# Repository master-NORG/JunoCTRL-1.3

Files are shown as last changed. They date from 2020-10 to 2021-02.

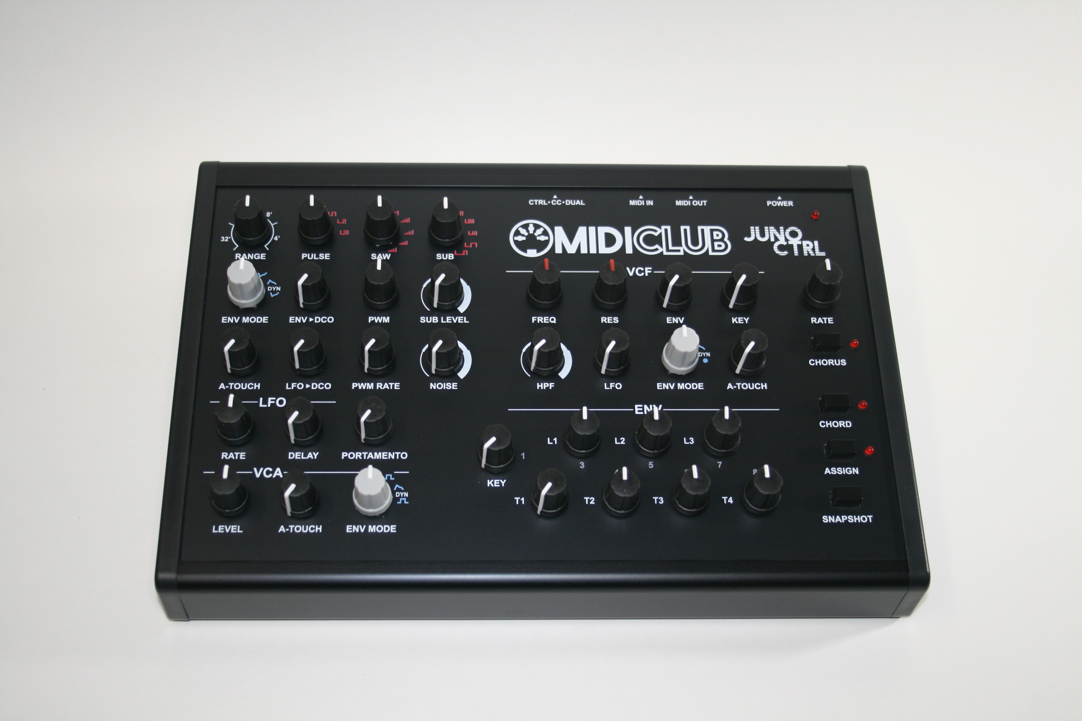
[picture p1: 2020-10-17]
JunoCTRL Photos/IMG_0346.JPG

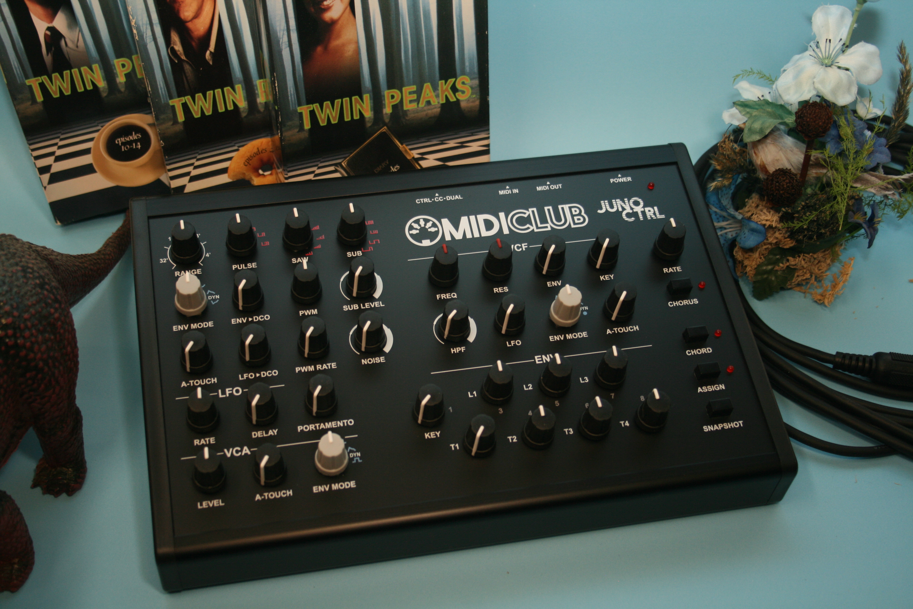
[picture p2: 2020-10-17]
JunoCTRL Photos/IMG_0430.JPG

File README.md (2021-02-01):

# JunoCTRL-1.3
Alpha Juno Hardware Controller

This is the repository for the JunoCTRL Alpha Juno controller from MIDI , which was released in 2015 and slowly upgraded and developed over the years until 2020.  You may use these files if you want to make your own JunoCTRL, modify your unit or would like to make a batch to bring down the price of components.  Be aware that I wrote the firmware 6 years ago when I knew almost nothing about C++ programming, it's awful to look at.  However, it works well, performs well and is bug-free.

I am not going to spend the time to document this project better, not that I don't want to, I just don't have the time. Although MIDI Club is no longer a thing, you can still reach us for questions about this project anytime at midiclub604@gmail.com

Note: there are two pcb boards, the main board and the smaller rear board for the switches, power and midi sockets. If you are making a JunoCTRL with the DIY acrylic case then you only need the main board and not the rear PCB.

Happy hacking!

-Dylan

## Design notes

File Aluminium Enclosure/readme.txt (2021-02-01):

send these files to Takashi Enclosure in Japan to have a case made.  CF27-18BB is the case we use, it's a sturdy black aluminium case.  Takashi Enclosure is great, I've never had a single issue with any of their orders and they are fast.

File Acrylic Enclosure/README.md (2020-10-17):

# junoctrl
JunoCTRL Acrylic Case Files

//In this folder are two files for making an acrylic laser cut case for the JunoCTRL.  They are Adobe Illustrator files and most laser cutting and printing service providers will be able to use these.  You will need to aquire one panel of 3mm thick (very important) matte acrylic and it must be approximately 21" x 12" in size.  I highly recommend using matte acrylic and not glossy, because glossy is too reflective and tends to pick up a lot of fingerprints and dust quickly.

//Printing**  You will need to print the graphics on the acrylic panel first before laser cutting.  The printing must be perfectly aligned since the laser cutting depends on it.  The graphics include a few cross hairs for proper alignment.  So for the type of printing we went with UV printing because it is the least expensive, however UV printing is not as permanent as screen printed graphics, so go with whichever method you prefer, either works fine.  If you do go with UV printing be very careful while transporting the printed panels to make sure the graphics don't get scratched off at any point. You will also notice in the printing file there is a layer that is all white and then the layers with colour, this is because the UV printing on black or dark colours needs a white surface to print on.  So the UV printer will do a layer of white and then the colour layers directly over top of them.

//Laser Cutting**  Most laser cutting service providers will be able to work with the large file, but keep in mind they must align it properly using the hair triggers to calibrate their cut.  The front panel is closet to the top of the file because this part must be cut as straight as possible, the side and rear panels do not need to be as perfect which is why they are near the bottom.

//Final notes** I have occasionally ordered 3mm plastic and received plastic that was 4.5mm thick.  If this is the case you may need to sand down the teeth on the pieces so everything fits.  Be sure the acrylic you order has no more than a +-0.5mm tolerance.

//Feel free to email me at info@midiclub.net if you have any questions regarding the process of making your own acrylic case for the JunoCTRL.  Cheers!  -Dylan

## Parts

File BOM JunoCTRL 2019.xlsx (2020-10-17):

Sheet: Sheet1
BOM JunoCTRL 2019
# | Qty |  | Part | Mrf: # | Source
D01 | 1 | A | 1N4148 Diode | 78-1N4148-TAP | Mouser
DC | 1 | A | DC Socket | 163-7620E-E | Mouser
IC01-04 | 4 | A | P to S Shift Registers (4021) | CD4021BE | Mouser
IC05 | 1 | A | S to P Shift Register (HC595) | SN74HC595N | Mouser
IC06-08 | 3 | A | Analog Multiplexers (4051) | 595-CD4051BE | Mouser
IC08 | 1 | A | Arduino Mini |  | eBay
IC07 | 1 | A | 6N138 Optocoupler | 6N138 | Mouser
L01-04 | 4 | A | 3mm Red LEDs | 859-LTL-4221 | Mouser
N01-02 | 2 | A | DIN-5 Sockets | 161-0504-28A-E | eBay
P01-29 | 29 | A | Rotary Pot 10k |  | Yuwah/Mouser
R01-04 | 4 | A | 2.21K Resistors | 660-MS1/4DCT52R2211 | Mouser
R05-07 | 3 | A | 220 Resistors | 660-MF1/4DCT52R2200F | Mouser
R08 | 1 | A | 1k Resistor | 660-MS1/4DCT52R1001 | Mouser
R09 | 1 | A | 470 Resistor | 660-MF1/4LCT52R471J | Mouser
RN01-04 | 4 | A | 10k 9-Pin Resistor Network | 652-4609X-1LF-10K | Mouser
S01-04 | 4 | N 52 | 4 pos Rotary Switch | SRBV141201 (https://ca.mouser.com/Search/ProductDetail.aspx) | Mouser/Chip1Stop/AVNet Express/E-sonic
S05-06 | 2 | A | 6 pos Rotary Switch | SRBV160803 | Mouser/Chip1Stop/AVNet Express/E-sonic
T01-04 | 4 | N 36 | Tactile Buttons | TL1100F160Q | Mouser/Digikey
W01 | 1 | A | DPDT Slide Switch | 612-EG2208A | Mouser
W02 | 1 | A | DP3T Slide Switch | 612-EG2310 | Mouser/Future Electronics
 | 30 |  | Knobs (Black) |  | Daier/Mouser
 | 3 |  | Knobs (Gray) |  | Daier/Mouser
 | 2 |  | Knobs (Red) |  | Daier/Mouser
 | 4 |  | Tact Switch Cap | 611-F1201 | Mouser
 | 4 | A | 6-32 screws | 36-9903-ND | Digikey
 | 1 |  | Power Supply | 552-PSM03A-090-R | AliExpress/Mouser/eBay/Lees | 9V Center-Positive (at least 400mA output) 2.21mm
 | 1 | A | PCB |  | Seedstudio/DirtyPCB
 | 1 |  | Cases |  | Takashi Enclosures
 | 8 | N 208 | 0.1uF 50v Ceramic Cap | 75-1C10Z5U104M050B | Mouser
 | 1 | A | 47uF 50v Electrolytic Cap | 647-UVZ1H470MED1TD | Mouser
D02 | 1 | A | 1n4002 Diode | 833-1N4002-TP | Mouser
 | 1 | A | L7805 Voltage Regulator | 511-L7805CV | Mouser
P02 | 1 |  | Metal Pot 10k Linear | 688-RK09L1140A66 | Mouser
 | 1 |  | 8 pin IC Sockets | 571-1-2199298-2 | Mouser
 | 8 |  | 16 pin IC Sockets | 571-1-2199298-4 | Mouser
 | 1 |  | Rear PCB board |  | Dirty PCBs
 | 2 |  | Angled Brackets | 36-4334-ND | Digikey | 4334 keystone
 | 4 |  | JST-Sockets |  | Digikey
 | 2 |  | JST-Wires PH8 20cm |  | Ali Express

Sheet: Sheet2
# | Qty |  | Part | x18 | Source | MRF #
D01 | 1 | A | 1N4148 Diode |  | Mouser
DC | 1 | A | DC Jack |  | Mouser
IC01-04 | 4 | A | P to S Shift Registers (4021) |  | Mouser
IC05 | 1 | A | S to P Shift Register (HC595) |  | Mouser
IC06-08 | 3 | A | Analog Multiplexers (4051) |  | Mouser
IC08 | 1 | A | Arduino Mini |  | eBay
IC07 | 1 | A | 6N138 Optocoupler |  | Mouser
L01-04 | 4 | A | 3mm Red LEDs |  | Mouser
N01-02 | 2 | A | DIN-5 Jacks |  | Mouser/Aliexpress
P01-29 | 29 | A | Rotary Pot 10k |  | Yuwah/Mouser
R01-04 | 4 | A | 2.21K Resistors |  | Mouser
R05-07 | 3 | A | 220 Resistors |  | Mouser
R08 | 1 | A | 1k Resistor |  | Mouser
R09 | 1 | A | 470 Resistor |  | Mouser
RN01-04 | 4 | A | 10k 9-Pin Resistor Network |  | Mouser
S01-04 | 4 | N 52 | 4 pos Rotary Switch |  | Mouser/Chip1Stop/AVNet Express
S05-06 | 2 | A | 6 pos Rotary Switch |  | Mouser/Chip1Stop/AVNet Express
T01-04 | 4 | N 36 | Tactile Buttons |  | Mouser/Digikey
W01 | 1 | A | DPDT Slide Switch |  | Mouser
W02 | 1 | A | DP3T Slide Switch |  | Mouser/Future Electronics
 | 30 |  | Knobs (Black) |  | Daier/Mouser
 | 3 |  | Knobs (Gray) |  | Daier/Mouser
 | 2 |  | Knobs (Red) |  | Daier/Mouser
 | 4 |  | Tact Switch Cap |  | Mouser
 | 6 | A | M3x9mm Spacers F/M |  | AliExpress/eBay
 | 7 | A | M3x22mm Spacers F/F |  | AliExpress/eBay
 | 4 | A | 6-32 screws |  | Ali Express
 | 4 |  | Rubber Feet |  | Mouser
 | 1 |  | Power Supply |  | AliExpress/Mouser/eBay/Lees
 | 1 | A | PCB |  | Seedstudio/DirtyPCB
 | 1 |  | Cases |  | Takashi Enclosures
 | 8 | N 208 | 0.1uF 50v Ceramic Cap |  | Mouser
 | 1 | A | 47uF 50v Electrolytic Cap |  | Mouser
D02 | 1 | A | 1n4002 Diode |  | Mouser
 | 1 | A | L7805 Voltage Regulator |  | Mouser
 | 1 |  | 8 pin IC Sockets |  | Mouser
 | 8 |  | 16 pin IC Sockets |  | Mouser
 | 1 |  | Rear PCB board |  | Dirty PCBs
 | 2 |  | Angled Brackets |  | Digikey
 | 2 |  | JST-Sockets |  | Ali Express
 | 2 |  | JST-Wires+Jacks |  | Ali Express

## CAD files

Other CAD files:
Aluminium Enclosure/SlidePanelMilling2.dwg
Aluminium Enclosure/RearPanelMilling.dwg

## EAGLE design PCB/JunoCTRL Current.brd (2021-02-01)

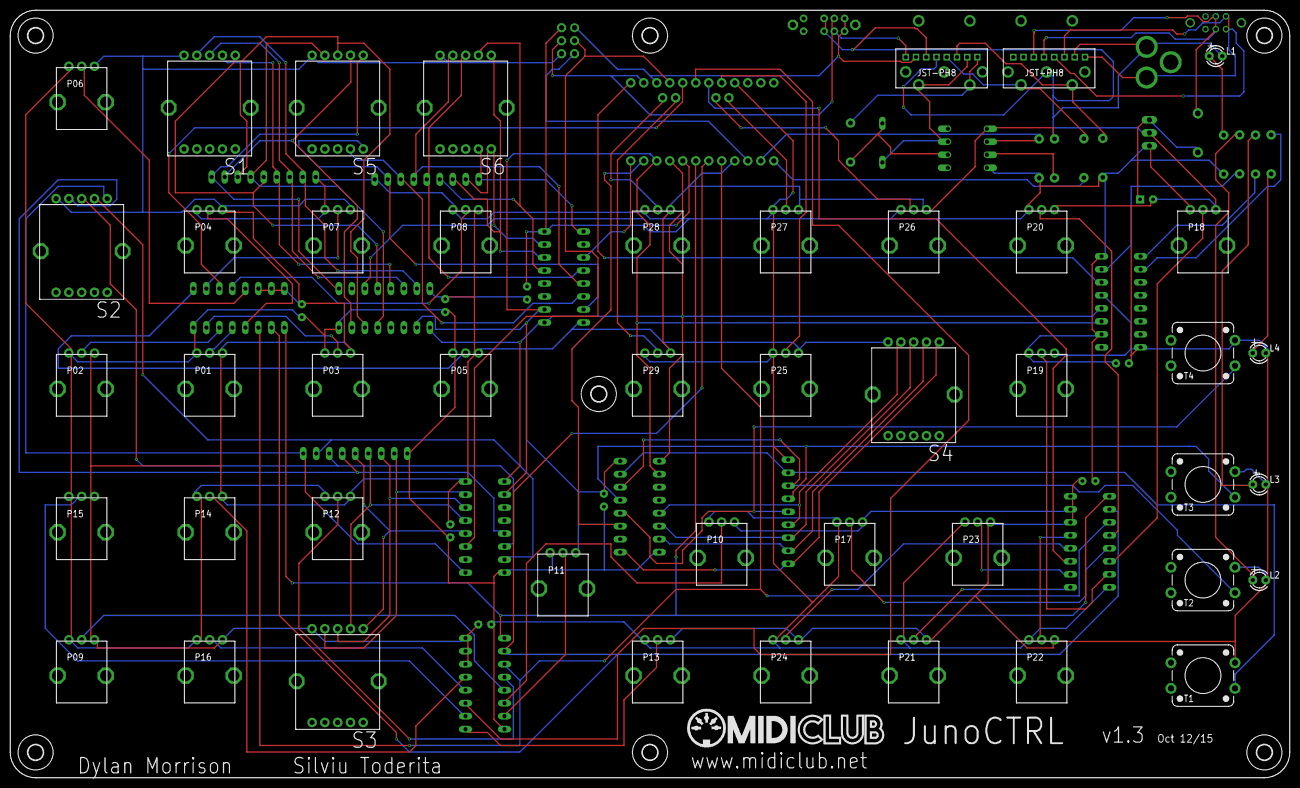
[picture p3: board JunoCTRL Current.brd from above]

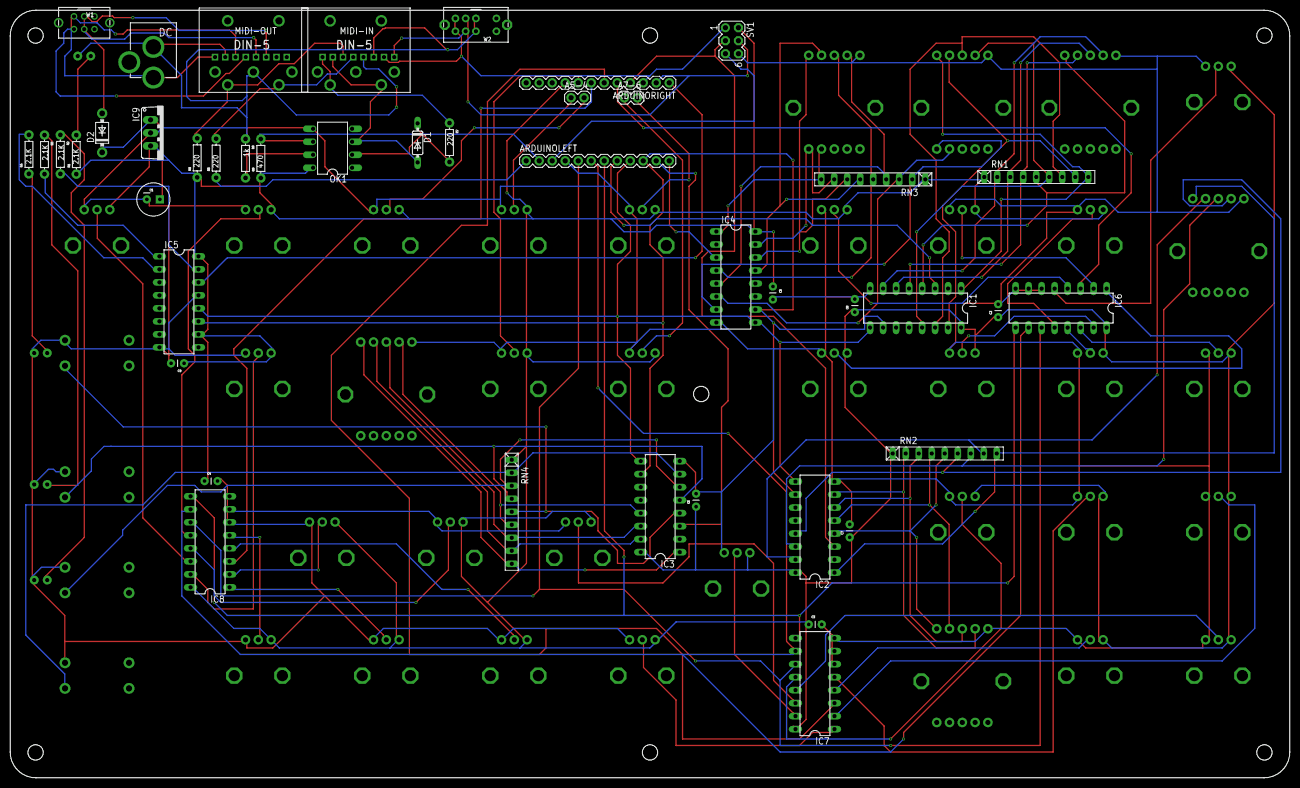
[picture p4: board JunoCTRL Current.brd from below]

Board: 2 copper layers, 249.9 x 149.9 mm, 96 parts (44 on the bottom side), 97 nets.

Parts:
A5-4, A7-6: 1X02
ARDUINOLEFT: 1X12
ARDUINORIGHT: 1X12
C1: 47uF; CPOL-RADIAL-100UF-25V
C2, C3, C4, C5, C6, C7, C8, C9: 0.1uF; CAP-PTH-SMALL
D1: 1N4148; DO35-7
D2: 1N4002; DO41-7
DC: POWER_JACKPTH; POWER_JACK_PTH
E$1, E$2: JSTCUSTOM_JST_PH8
IC1, IC2, IC3, IC4: 4021N; DIL16
IC5: 74HC595N; DIL16
IC6, IC7, IC8: 4051N; DIL16
IC9: 7805TV; TO220V
L1, L2, L3, L4: LED3MM
MIDI-IN: MIDI_CONN_FEMALE_SUPPORT; DIN_5_FEMALE_SUPPORT
MIDI-OUT: MIDI_CONN_FEMALE_SUPPORT; DIN_5_FEMALE_SUPPORT
OK1: 6N138; DIL08
P01, P02, P03, P04, P05, P06, P07, P08, P09, P10, P11, P12, P13, P14, P15, P16, P17, P18, P19, P20, P21, P22, P23, P24, P25, P26, P27, P28, P29: 10K; ALPS_POT
R1, R2, R3, R4: 2.1K; AXIAL-0.3
R5, R6, R7: 220; AXIAL-0.3
R8: 1k; AXIAL-0.3
R9: 470; AXIAL-0.3
RN1, RN2, RN3, RN4: 10k; RN-9
S1, S2, S3, S4: 4Pos; SRBV
S5, S6: 6Pos; SRBV
SV1: MA03-2
T1, T2, T3, T4: TACTILE-PTH-12MM
U$1, U$2, U$3, U$4, U$5, U$6, U$7: 3,0
W1: 0S-SPDT
W2: 0S-SP3T

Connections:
GND: ARDUINOLEFT.4, C1.2, C2.2, C3.2, C4.2, C5.2, C6.2, C7.2, C8.2, C9.2, DC.GND, E$1.P$5, E$1.P$6, E$2.P$2, IC1.8, IC2.8, IC3.8, IC4.8, IC5.8, IC5.13, IC6.6, IC6.7, IC6.8, IC7.6, IC7.7, IC7.8, IC8.6, IC8.7, IC8.8, IC9.2, L1.K, L2.K, L3.K, L4.K, MIDI-OUT.2, OK1.5, P01.P$1, P02.P$1, P03.P$1, P04.P$1, P05.P$1, P06.P$1, P07.P$1, P08.P$1, P09.P$1, P10.P$1, P11.P$1, P12.P$1, P13.P$1, P14.P$1, P15.P$1, P16.P$1, P17.P$1, P18.P$1, P19.P$1, P20.P$1, P21.P$1, P22.P$1, P23.P$1, P24.P$1, P25.P$1, P26.P$1, P27.P$1, P28.P$1, P29.P$1, R8.P$1, S1.1, S2.1, S3.1, S4.1, S5.1, S6.1, SV1.6, T1.3, T2.3, T3.3, T4.3, W2.PA2, W2.PA6
unnamed: IC7.4, P16.P$2
unnamed: IC6.4, P08.P$2
unnamed: IC6.2, P07.P$2
unnamed: IC6.5, P06.P$2
unnamed: IC6.1, P05.P$2
unnamed: IC6.12, P04.P$2
unnamed: IC6.15, P03.P$2
unnamed: IC6.14, P02.P$2
unnamed: IC6.13, P01.P$2
unnamed: IC7.2, P15.P$2
unnamed: IC7.5, P14.P$2
unnamed: IC7.1, P13.P$2
unnamed: IC7.12, P12.P$2
unnamed: IC7.15, P11.P$2
unnamed: IC7.14, P10.P$2
unnamed: IC7.13, P09.P$2
unnamed: IC8.4, P24.P$2
unnamed: IC8.2, P23.P$2
unnamed: IC8.5, P22.P$2
unnamed: IC8.1, P21.P$2
unnamed: IC8.12, P20.P$2
unnamed: IC8.15, P19.P$2
unnamed: IC8.14, P18.P$2
unnamed: IC8.13, P17.P$2
unnamed: ARDUINORIGHT.8, P25.P$2
unnamed: A5-4.2, P26.P$2
unnamed: A5-4.1, P27.P$2
unnamed: A7-6.2, P28.P$2
unnamed: A7-6.1, P29.P$2
unnamed: ARDUINOLEFT.5, IC6.11, IC7.11, IC8.11
unnamed: ARDUINOLEFT.6, IC6.10, IC7.10, IC8.10
unnamed: ARDUINOLEFT.7, IC6.9, IC7.9, IC8.9
unnamed: ARDUINORIGHT.5, IC6.3
unnamed: ARDUINORIGHT.6, IC7.3
unnamed: ARDUINORIGHT.7, IC8.3
unnamed: IC1.7, RN1.2, S1.2
unnamed: IC1.6, RN1.3, S1.3
unnamed: IC1.5, RN1.4, S1.4
unnamed: IC1.4, RN1.5, S1.5
unnamed: IC1.13, RN1.6, S5.2
unnamed: IC1.14, RN1.7, S5.3
unnamed: IC1.15, RN1.8, S5.4
unnamed: IC1.1, RN1.9, S5.5
unnamed: IC2.7, RN2.2, S3.2
unnamed: IC2.6, RN2.3, S3.3
unnamed: IC2.5, RN2.4, S3.4
unnamed: IC2.4, RN2.5, S3.5
unnamed: IC2.13, RN2.6, S2.2
unnamed: IC2.14, RN2.7, S2.3
unnamed: IC2.15, RN2.8, S2.4
unnamed: IC2.1, RN2.9, S2.5
unnamed: OK1.7, R8.P$2
unnamed: IC4.7, RN3.2, S5.6
unnamed: IC4.6, RN3.3, S5.7
unnamed: IC4.5, RN3.4, S6.2
unnamed: IC4.4, RN3.5, S6.3
unnamed: IC4.13, RN3.6, S6.4
unnamed: D2.A, E$2.P$5, E$2.P$6, W1.P1C, W1.P2C
unnamed: IC4.14, RN3.7, S6.5
unnamed: IC4.15, RN3.8, S6.6
unnamed: ARDUINORIGHT.3, E$1.P$7, SV1.1, W2.PA4, W2.PA8
unnamed: L1.A, R1.P$2
unnamed: ARDUINORIGHT.2, E$1.P$8, SV1.4, W2.PA3, W2.PA7
unnamed: IC5.15, R2.P$2
unnamed: L2.A, R2.P$1
unnamed: ARDUINORIGHT.1, IC5.14
unnamed: DC.PWR, E$2.P$1, E$2.P$3, E$2.P$4, W1.P1T2, W1.P2T2
unnamed: L3.A, R3.P$1
unnamed: ARDUINORIGHT.4, IC2.3, SV1.3
unnamed: E$1.P$1, MIDI-IN.4, R7.P$1
unnamed: D1.A, E$1.P$2, MIDI-IN.5, OK1.3
unnamed: C1.1, D2.C, IC9.1
unnamed: ARDUINOLEFT.2, OK1.6, R9.P$2
unnamed: E$1.P$4, MIDI-OUT.5, R5.P$2
unnamed: ARDUINOLEFT.1, R5.P$1
unnamed: E$1.P$3, MIDI-OUT.4, R6.P$2
unnamed: IC4.1, RN3.9, S6.7
unnamed: IC3.7, RN4.2, T1.1
unnamed: IC3.6, RN4.3, T2.1
unnamed: IC3.5, RN4.4, T3.1
unnamed: IC3.4, RN4.5, T4.1
unnamed: IC5.1, R3.P$2
unnamed: IC5.2, R4.P$2
unnamed: L4.A, R4.P$1
unnamed: D1.C, OK1.2, R7.P$2
unnamed: IC3.13, RN4.6, S4.2
unnamed: IC3.14, RN4.7, S4.3
unnamed: IC3.15, RN4.8, S4.4
unnamed: IC3.1, RN4.9, S4.5
unnamed: ARDUINOLEFT.3, SV1.5
SR5: ARDUINOLEFT.8, IC1.3
SR6: ARDUINOLEFT.9, IC1.9, IC2.9, IC3.9, IC4.9, IC5.12
SR7: ARDUINOLEFT.10, IC1.10, IC2.10, IC3.10, IC4.10, IC5.11
SR8: ARDUINOLEFT.11, IC3.3
SR9: ARDUINOLEFT.12, IC4.3
VCC: ARDUINORIGHT.9, C2.1, C3.1, C4.1, C5.1, C6.1, C7.1, C8.1, C9.1, IC1.16, IC2.16, IC3.16, IC4.16, IC5.10, IC5.16, IC6.16, IC7.16, IC8.16, IC9.3, OK1.8, P01.P$3, P02.P$3, P03.P$3, P04.P$3, P05.P$3, P06.P$3, P07.P$3, P08.P$3, P09.P$3, P10.P$3, P11.P$3, P12.P$3, P13.P$3, P14.P$3, P15.P$3, P16.P$3, P17.P$3, P18.P$3, P19.P$3, P20.P$3, P21.P$3, P22.P$3, P23.P$3, P24.P$3, P25.P$3, P26.P$3, P27.P$3, P28.P$3, P29.P$3, R1.P$1, R6.P$1, R9.P$1, RN1.1, RN2.1, RN3.1, RN4.1, SV1.2

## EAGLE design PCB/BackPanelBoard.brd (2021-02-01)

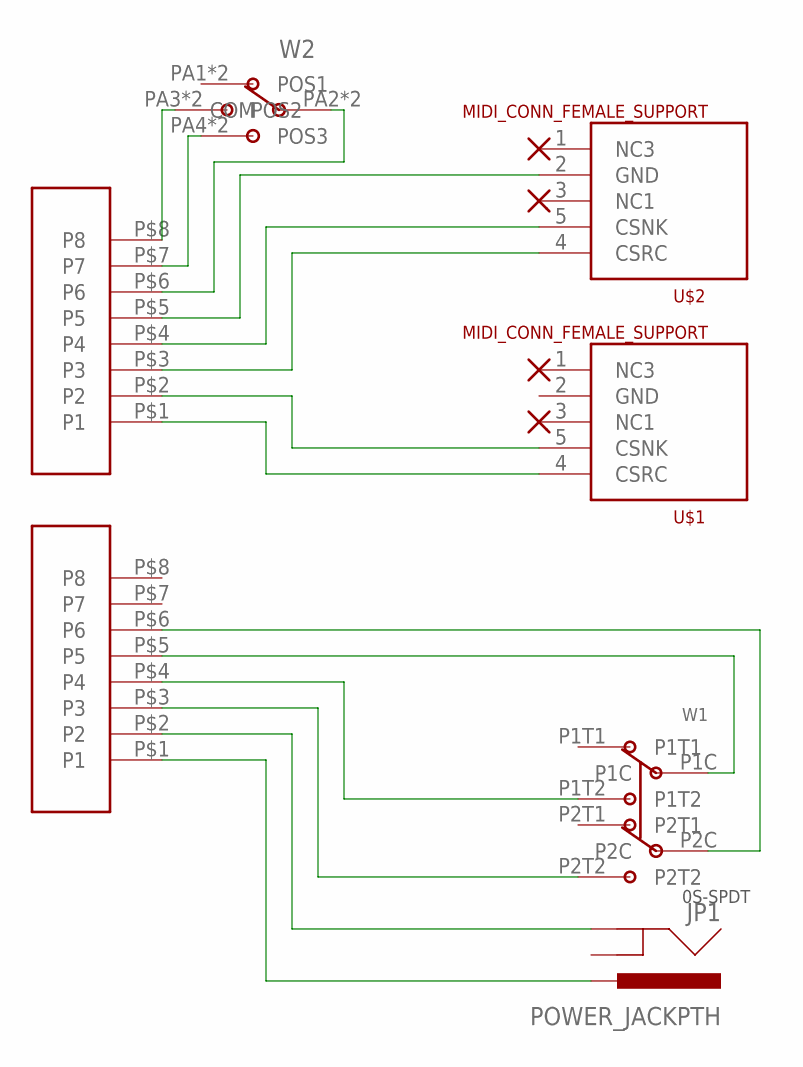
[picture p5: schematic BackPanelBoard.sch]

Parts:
JP1: POWER_JACKPTH; POWER_JACK_PTH
U$1, U$2: MIDI_CONN_FEMALE_SUPPORT; DIN_5_FEMALE_SUPPORT
U$3, U$4: JST_PH8THROUGH_HOLE; JST_PH8
W1: 0S-SPDT
W2: 0S-SP3T

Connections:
unnamed: U$1.4 (CSRC), U$3.P$1 (P1)
unnamed: U$1.5 (CSNK), U$3.P$2 (P2)
unnamed: U$2.4 (CSRC), U$3.P$3 (P3)
unnamed: U$2.5 (CSNK), U$3.P$4 (P4)
unnamed: U$2.2 (GND), U$3.P$5 (P5)
unnamed: JP1.PWR, U$4.P$1 (P1)
unnamed: JP1.GND, U$4.P$2 (P2)
unnamed: U$4.P$3 (P3), W1.P2T2
unnamed: U$4.P$4 (P4), W1.P1T2
unnamed: U$4.P$5 (P5), W1.P1C
unnamed: U$4.P$6 (P6), W1.P2C
unnamed: U$3.P$6 (P6), W2.PA2 (COM), W2.PA6 (COM)
unnamed: U$3.P$7 (P7), W2.PA4 (POS3), W2.PA8 (POS3)
unnamed: U$3.P$8 (P8), W2.PA3 (POS2), W2.PA7 (POS2)

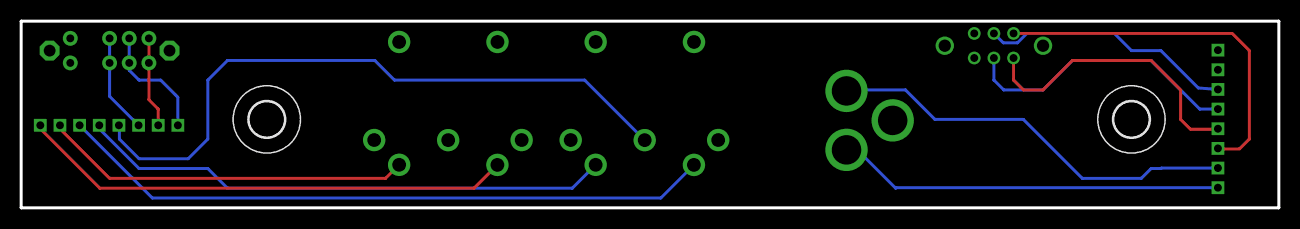
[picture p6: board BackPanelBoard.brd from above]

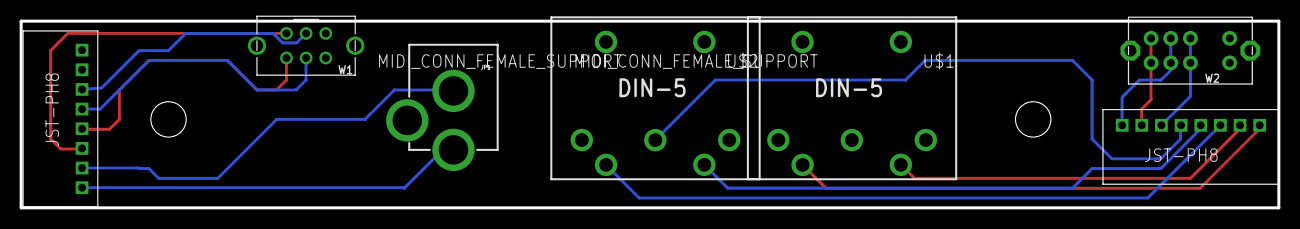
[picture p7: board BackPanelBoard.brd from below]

Board: 2 copper layers, 128.0 x 19.0 mm, 9 parts (7 on the bottom side), 14 nets.

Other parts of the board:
U$7, U$8: 3,6

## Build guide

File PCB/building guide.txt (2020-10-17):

1. IC Sockets!  This must be done first before anything
2. Resistors, 220, 2.2K, 470 ohm, 1K, Diodes, Ceramic Capacitors (little yellow guys), tactile buttons
3. Resistor Networks (square yellow things, MUST BE PUT THE CORRECT ORIENTATION)
4. Voltage regulator, Electrolytic Capacitor
5. Side JST PH sockets (white ribbon cable sockets)
6. 6-position rotary switches (two of them, and make sure to put them in the right spot, they are ridiculously expensive)
7. Potentiometers
8. 4-position rotary switches (four of them)
9. Red Leds
10. Header sockets for arduino
11.You are now finished the main board, yay. Now do the back panel PCB.

Back Panel:
1. Start with JST top sockets
2. 2-position and 3-position switches, do not overheat.
3. DC Socket, make sure it's straight and lots of solder
4. Midi Sockets, make sure flush against board

All done, attach the ribbon cable.

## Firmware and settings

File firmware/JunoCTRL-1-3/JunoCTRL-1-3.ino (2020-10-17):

#include <EEPROM.h>

//unsigned long hertz = 0;
//long start;
//byte startBlock;
byte brown;
byte initNoteFix = 0;

// Variables for potentiometer functions

const byte analogPin0 = 0;
const byte analogPin1 = 1;
const byte analogPin2 = 2;
const byte analogPin3 = 3;
const byte analogPin4 = 4;
const byte analogPin5 = 5;
const byte analogPin6 = 6;
const byte analogPin7 = 7;

const byte select[] = {2,3,4};
byte getTemp;

byte paramChange[7] = {240,65,54,0,35,32,1};
byte snapShot[7] = {240,65,53,0,35,32,1};

const byte test[3] = {144, 80, 80};

int paramList[36];
int paramValue;
int paramValueCC;
int potSwitch;
int potSwitchVal;
byte allowPotSwitch;
byte all2 = 1;

byte ccModeSelect;

byte potCounter = 0;

byte potParamChart[29] = {11,13,15,12,8,6,14,7, 22,27,33,35,26,25,24,23, 29,34,21,20,30,32,31,28, 18,19,17,16,9};

int rawReadArray[29];

byte potEnable = 0;
byte readBlock = 1;
int low2;
int high2;

byte channel;
int value;
int rawRead;
byte whichAnalogPin;
byte whichParam;
byte lastParam = 128;

#define sbi(sfr, bit) (_SFR_BYTE(sfr) |= _BV(bit))

//Variables for buttons and leds

int RWcount = 0;

byte ledStateArray[8] = {0,0,0,0,0,0,0,0};

byte ledT2state;
byte ledT3state;
byte ledT4state;
byte ledT5state;

byte butStateT1 = LOW;
byte butStateT2 = LOW;
byte butStateT3 = LOW;
byte butStateT4 = LOW;
byte butStateT5 = LOW;

byte LbutStateT1 = LOW;
byte LbutStateT2 = LOW;
byte LbutStateT3 = LOW;
byte LbutStateT4 = LOW;
byte LbutStateT5 = LOW;

long LdebTimeT1 = 0;
long LdebTimeT2 = 0;
long LdebTimeT3 = 0;
long LdebTimeT4 = 0;
long LdebTimeT5 = 0;
long debdelay = 40;

//MIDI CC OUTPUT MODE related variables

byte chanList[16] = {176,177,178,179,180,181,182,183,184,185,186,187,188,189,190,191};
byte chanSelect;

byte ccList[37];

byte ModPosSwitch;


//Variables for switch functions

const byte latchPin = 6;
const byte clockPin = 7;
const byte dataPin0 = 5;
const byte dataPin1 = 13;
const byte dataPin2 = 8;
const byte dataPin3 = 9;
const byte dataPin4 = 10;

byte dByte;
byte bByte;

byte shiftdata0[8];
byte shiftdata1[8];
byte shiftdata2[8];
byte shiftdata3[8];
byte shiftdata4[8];

byte byteVal;
int RWcounter = 7;
byte digEnable = 0;
byte latchEn = 1;


//MIDI IN

byte incomingByte;
byte lastIncomingByte = 249;
byte lastIncomingByte2 = 249;

byte ChanMessages[3];
byte xbyte = 1;
byte allow;
byte allow1 = 0;
byte twobyteChan;

int sysCounter = 0;
byte SysMessages[255];

int longSys = 0;
int longCount = 0;
int longOn = 0;
int maxCount = 0;

//CC Conversion Stuff

int paramConA[36];
int paramConB[36];
int conCount1 = 0;
byte conCCList[37];
byte conCCMessages[2];

byte whichCC;
int conCounter = 1;
int lasttemp = 0;
byte lastCCpack[2] = {140, 140};

byte chanListIn[16] = {176,177,178,179,180,181,182,183,184,185,186,187,188,189,190,191};
byte chanSelectIn;

byte allow2 = 0;
byte allow3 = 1;
byte openGate = 0;

//DUAL MODE variables

byte dualModeOn = 1;

byte dualNoteOff[16] = {128,129,130,131,132,133,134,135,136,137,138,139,140,141,142,143};      //zstatus
byte dualNoteOn[16] = {144,145,146,147,148,149,150,151,152,153,154,155,156,157,158,159};
byte dualAftertouch[16] = {160,161,162,163,164,165,166,167,168,169,170,171,172,173,174,175};
byte dualCC[16] = {176,177,178,179,180,181,182,183,184,185,186,187,188,189,190,191};
byte dualProgram[16] = {192,193,194,195,196,197,198,199,200,201,202,203,204,205,206,207};
byte dualChanAfter[16] = {208,209,210,211,212,213,214,215,216,217,218,219,220,221,222,223};
byte dualPitchBend[16] = {224,225,226,227,228,229,230,231,232,234,235,236,237,238,239};

byte dualChannelSelect;

byte modPosVar1;
byte modPosVar2;


//ASSIGN variables

byte assignCounter = 0;
byte assignCount = 0;
byte assignOn = 0;
byte assignKnobSelect = 36;
int assignFlashDelay = 0;
int assignFlash = 0;

int assignLastFlash;

byte middleCpressed = 0;

int assignGateOpen = 0;
int assignGateOpen2 = 0;
int assignFlip = 0;

int secondByteAllow = 0;

int assignVal[5];

int assignVal2;

byte tempAllow = 1;
byte assignHeld = 0;

byte trigger = 0;
byte disableSysCon = 0;
long disableClock;

//Chord memory related

byte tempSet = 1;
byte chordHold = 0;
byte assignHold = 0;
byte lightSet = 0;
byte chordMemory;
byte chCount[8];
byte lastChordCount;
//byte chordValtemp[5];

byte chSelect;

byte chord1[5];
byte chord2[5];
byte chord3[5];
byte chord4[5];
byte chord5[5];
byte chord6[5];
byte chord7[5];
byte chord8[5];


byte readingT3;
byte chordTemp;
byte chordAllow = 0;
byte noteOff = 0;

byte notesOn = 0;

byte tempCount = 1;
byte tempdeny = 1;
byte currentNote = 128;
byte chordNotes[6] = {128,128,128,128,128,128};

byte letgo = 1;
byte snapHold = 0;
byte monoChords;
byte lightup = 0;
byte offAllow;

int doubleVal0;
byte doubleSave0;
byte doubleYes0;
int doubleOrig0;

int doubleVal0cc;
byte doubleSave0cc;
byte doubleYes0cc;
int doubleOrig0cc;

int doubleVal1;
byte doubleSave1;
byte doubleYes1;
int doubleOrig1;

int doubleVal1cc;
byte doubleSave1cc;
byte doubleYes1cc;
int doubleOrig1cc;

byte lastModReading;

byte whichChan;
byte chordArray[10] = {128,128,128,128,128,128,128,128,128,128};
byte blockRemove = 1;
byte noteCount = 0;
byte noteMute = 0;

byte tempChordMem;

int chordValtemp1[6];
int chordVal1[6];
byte lowestVal[8];
int add = 0;


//snapshot vars

byte ssArray[108];
byte snapC = 0;
byte ssOpen = 0;
long ssLastMillis;
byte snap2 = 0;

byte dualCCswitched = 0;
byte blockParse = 1;
                                                                              //------------------------------
                                                        //---------------------------------------------
//Functions ----------------------------------------------------------------------------
                                                                      //---------------------------------------------
                                                                                //-------------------------------------
/*
   *⦁ int getValue1(int channel, int analogPin) {
    ⦁ int formatVal(int channel, int value) {
    ⦁ int formatPotSwitchCC(int which, int value) {
    ⦁ int fourPos(byte input) {
    ⦁ int sixPos(byte input) { 
    ⦁ int fourPosCC(int input) { 
    ⦁ byte formatConVal(byte which, byte value) {
    ⦁ void chordSave(int whichNote) {
    ⦁ void ReadWrite() {
    ⦁ void SysexCon2()
    ⦁ void SysexConversion() {
    ⦁ void MidiParsing() {
    ⦁ void longSysFunc() {
    ⦁ void whichChanFunc() {
    ⦁ void regChordMem(int whichNote) {
    ⦁ void findLowest() {
    ⦁ void factoryDefault() {
    ⦁ void SuperAnalogRead() {
    ⦁ void WhichStuff() { 
    ⦁ void chBankWrite(byte chSelect,int i,byte newVal) {
    ⦁ byte chBankRead(byte chSelect,int i) {
    ⦁ modpos() {
 */

int getValue1(int channel, int analogPin) { //zget

  //if(potEnable != 1) {                   //this was for when we were testing the unit reading each value twice and taking the second one

    if (analogPin < 3) {              //if the reading is of a pot connected to a multiplexer this makes the digital outs send the current channel number to the multiplexers
      getTemp = (byte)channel << 2;        //shifts the channel 2 to the left, 000,001,010,011,100,101,111
      PORTD &= B11100011;    //clears the register where the channel value goes
      PORTD = PORTD | getTemp;       //puts the channel in binary to the digital out registers  
      
    }

      #if defined(ADCSRB) && defined(MUX5)
      // the MUX5 bit of ADCSRB selects whether we're reading from channels
      // 0 to 7 (MUX5 low) or 8 to 15 (MUX5 high).
      ADCSRB = (ADCSRB & ~(1 << MUX5)) | (((analogPin >> 3) & 0x01) << MUX5);
      #endif
      
      // set the analog reference (high two bits of ADMUX) and select the
      // channel (low 4 bits).  this also sets ADLAR (left-adjust result)
      // to 0 (the default).
      #if defined(ADMUX)
      ADMUX = (DEFAULT << 6) | (analogPin & 0x07);
      #endif
  //}
  

  // start the conversion
  sbi(ADCSRA, ADSC);
  
}



int formatVal(int channel, int value) {    //takes the value and channel number and formats the value into what the sysex input will accept on the alphajuno
  int fvalue;
  int tvalue;
  if (channel > 10 && channel < 35) {
    fvalue = value / 8;
  } else {
    if (channel > 6 && channel < 10) {
      if (value < 216) {
        fvalue = 0;
      } else {
        if (value > 215 && value < 532) {
          fvalue = 1;
        } else {
          if (value > 531 && value < 828) {
            fvalue = 2;
          } else {
            if (value > 827) {
              fvalue = 3;
            }
          }
        }
      }
    } else {
      if (channel == 6) {
        if (value < 216) {
          fvalue = 3;
        } else {
          if (value > 215 && value < 532) {
            fvalue = 2;
          } else {
            if (value > 531 && value < 828) {
              fvalue = 1;
            } else {
              if (value > 827) {
                fvalue = 0;
              }
            }
          }
        }
      } else {
      if (channel == 4 || channel == 5) {
        fvalue = value / 171;    //note: not perfectly even, 1024 is not divisible by 6
      } else {
        if (channel == 10) {
          fvalue = value / 512;
        } else {
          if (channel == 35) {
            fvalue = value / 79;    //note: not perfectly even, 1024 is not divisible by 13
          }
        }
      }
    }
    }
  }
  return fvalue;
}

int formatPotSwitchCC(int which, int value) {
  int fvalue;
  if (which > 6 && which < 10) {
    if (ccModeSelect || ModPosSwitch == 2) {
    if (value < 216) {
      fvalue = 0;
    } else {
      if (value > 215 && value < 532) {
        fvalue = 43;
      } else {
        if (value > 531 && value < 828) {
          fvalue = 85;
        } else {
          if (value > 827) {
            fvalue = 127;
          }
        }
      }
    }
    } else {
      fvalue = value / 8;  //this is what you would remove to delete this cc type thang
    }
  } else {
    if (which == 6) {
      if (ccModeSelect || ModPosSwitch == 2) {
    if (value < 216) {
      fvalue = 127;
    } else {
      if (value > 215 && value < 532) {
        fvalue = 85;
      } else {
        if (value > 531 && value < 828) {
          fvalue = 43;
        } else {
          if (value > 827) {
            fvalue = 0;
          }
        }
      }
    }
    } else {
      fvalue = value / 8;
    }
  } else {
    fvalue = value / 8;
  }
  }
    return fvalue;
}


int fourPos(byte input) {    //just makes 0 into position 3 for the 4 pos switch
  int output;
  if (input == 8) {
    output = 3;
  } else {
    if (input == 4) {
      output = 2;
    } else {
      if (input == 0) {
        output = 4;
      } else {
        output = (int)input - 1;
      }
    }
  }
  return output;
}

int sixPos(byte input) {    //just makes 0 into position 5 for the 6 pos switch
  int output;
  if (input == 32) {
    output = 5;
  } else {
    if (input == 4) {
      output = 2;
    } else {
      if (input == 8) {
        output = 3;
      } else {
        if (input == 16) {
          output = 4;
        } else {
          if (input == 0) {
            output = 6;
          } else {
            output = (int)input - 1;
          }
        }
      }
    }
  }
  return output;
}

int fourPosCC(int input) {      // converts switch value to it's proper midi cc format to be outputted
  int output;
      switch (input) {
        case 0:
          output = 0;
          break;
        case 1:
          output = 43;
          break;
        case 2:
          output = 85;
          break;
        case 3:
          output = 127;
          break;
      }
  return output;
}

int sixPosCC(int input) {      //coverts to cc values for 6 pos switch
  int output;
      switch (input) {
        case 0:
          output = 0;
          break;
        case 1:
          output = 26;
          break;
        case 2:
          output = 51;
          break;
        case 3:
          output = 77;
          break;
        case 4:
          output = 102;
          break;
        case 5:
          output = 127;
          break;
      }
  return output;
}
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
void loop() {  //zloop
  
  
bByte = PINB;
modPosVar1 = !bitRead(bByte, 3);    //the mode switch is connected directly to arduino pins
modPosVar2 = !bitRead(bByte, 4);
//modPosVar1 = !digitalRead(11);
//modPosVar2 = !digitalRead(12);

modPos();


whichChanFunc();

//----------------MIDI ASSIGN MODE ON -------->>>>>>>>>>>>>>>>>>>>>>>>>>
  if (chordHold && assignHold) {  // this is the chord assign loop  zcassign
    lightSet = 0;
    tempChordMem = chordMemory;
    chordMemory = 0;
    lastChordCount = chCount[chSelect];
    chCount[chSelect] = 0;
  }
  while(chordHold && assignHold) {      //CHORD BANK ASSIGN MODE!!
    //RWcount = 0;      //don't need the extra speed in this loop, so don't need to alternate the reads
    
    bByte = PINB;
    modPosVar1 = !bitRead(bByte, 3);
    modPosVar2 = !bitRead(bByte, 4);
    //modPosVar1 = !digitalRead(11);
    //modPosVar2 = !digitalRead(12);
    
    modPos();
    
    whichChanFunc();
    
      if (potCounter > 28) {
        potCounter = 0;
      } 
      
      if (conCount1 > 17) {
        conCount1 = 0;
      }
      if (lightSet == 0) {
        assignLastFlash = millis();
          ledT2state = 1;                //turn on t2 and t3 lights
          ledT3state = 1;
          ledStateArray[0] = ledT2state;
          ledStateArray[1] = ledT3state;
          ledStateArray[2] = ledT4state;
          
          middleCpressed = 0;
          lightSet = 1;
      }
          
        assignFlash = millis();                      //flash lights after reference note pressed
        if ((assignFlash - assignLastFlash) > 250) {
          ledT2state = !ledT2state; // no eeprom save here necessary
          ledT3state = !ledT3state;
          assignLastFlash = assignFlash;
        }
      
      if (lightup == 0) {                  //once 5 notes are pressed, then lights stay on
        ledStateArray[0] = ledT2state;
        ledStateArray[1] = ledT3state;
        ledStateArray[2] = ledT4state;
      } else {
        ledStateArray[0] = 1;           
        ledStateArray[1] = 1;
        ledStateArray[2] = 1;
      }
      
      ReadWrite();
      
      

          
   
      
      
    WhichStuff();
    SuperAnalogRead();
    
    if (potEnable) {
                //paramValues get updated, but after exiting chord assign mode new values are not sent out of the controller
      if ((rawReadArray[potCounter] < (paramList[whichParam] - 6)) || (rawReadArray[potCounter] > (paramList[whichParam] + 6))) {
        if ((rawReadArray[potCounter] / 8) != (paramList[whichParam] / 8)) {
          paramList[whichParam] = rawReadArray[potCounter];
        
        if(whichParam > 25 && whichParam < 34) {      //envelope knobs are turned to select which chord from 8 chord bank
          

          
          if (chCount[chSelect] == 0 || chCount[chSelect] == 1) {    //if no real chord is made
                        chCount[chSelect] = lastChordCount;  //reverts chordcount back to original
                        int which;
                        switch(chSelect) {
                            case 0:
                              which = 6;
                              break;
                            case 1:
                              which = 103;
                              break;
                            case 2:
                              which = 108;
                              break;
                            case 3:
                              which = 113;
                              break;
                            case 4:
                              which = 118;
                              break;
                            case 5:
                              which = 123;
                              break;
                            case 6:
                              which = 128;
                              break;
                            case 7:
                              which = 133;
                              break;
                          }
                        for (int i=0;i<5;i++) {
                          int which2 = which + i;
                          chBankWrite(chSelect,i,EEPROM.read(which2));    //reverts chord notes back to last set
                        }
                      } else {      //if an actual chord is pressed
                          findLowest();
                          chCount[chSelect]--;
                          int add = 0;
                          for (int i=0;i<6;i++) {
                            int temp = i - add;
                            if (chordVal1[i] != lowestVal[chSelect]) {
                              chBankWrite(chSelect,temp,chordVal1[i]);  //sets new values to chord
                            } else {
                              add = 1;
                            }
                          }
                          int which;
                          switch(chSelect) {
                            case 0:
                              which = 6;
                              break;
                            case 1:
                              which = 103;
                              break;
                            case 2:
                              which = 108;
                              break;
                            case 3:
                              which = 113;
                              break;
                            case 4:
                              which = 118;
                              break;
                            case 5:
                              which = 123;
                              break;
                            case 6:
                              which = 128;
                              break;
                            case 7:
                              which = 133;
                              break;
                          }
                          for (int i=0;i<5;i++) {
                            int which2 = which + i;
                            EEPROM.write(which2,chBankRead(chSelect,i));
                          }
                          switch(chSelect) {
                            case 0:
                              EEPROM.write(138,chCount[chSelect]);
                              EEPROM.write(102,chSelect);
                              break;
                            case 1:
                              EEPROM.write(139,chCount[chSelect]);
                              EEPROM.write(102,chSelect);
                              break;
                            case 2:
                              EEPROM.write(140,chCount[chSelect]);
                              EEPROM.write(102,chSelect);
                              break;
                            case 3:
                              EEPROM.write(141,chCount[chSelect]);
                              EEPROM.write(102,chSelect);
                              break;
                            case 4:
                              EEPROM.write(142,chCount[chSelect]);
                              EEPROM.write(102,chSelect);
                              break;
                            case 5:
                              EEPROM.write(143,chCount[chSelect]);
                              EEPROM.write(102,chSelect);
                              break;
                            case 6:
                              EEPROM.write(144,chCount[chSelect]);
                              EEPROM.write(102,chSelect);
                              break;
                            case 7:
                              EEPROM.write(145,chCount[chSelect]);
                              EEPROM.write(102,chSelect);
                              break;
                          }
                          
                          EEPROM.write((chSelect+93), lowestVal[chSelect]);
                        }
                        
                        
          if (whichParam == 33) {
            chSelect = 0;
          } else {
           chSelect = whichParam - 25; 
          }

          lightup = 0;
          
          lastChordCount = chCount[chSelect];
          chCount[chSelect] = 0; 
          
        }
        
        //if which param is one of the 8 envelope knobs then switch to that bank and reset the chordcount variable 
      }
    }

    potEnable = 0;
    potCounter++;
    }
    
    
          
      SysexCon2();
         
      if (Serial.available() > 0) {
        incomingByte = Serial.read();
        
         SysexConversion();
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

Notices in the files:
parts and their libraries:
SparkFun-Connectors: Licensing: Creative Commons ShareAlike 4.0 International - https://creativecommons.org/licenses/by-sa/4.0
